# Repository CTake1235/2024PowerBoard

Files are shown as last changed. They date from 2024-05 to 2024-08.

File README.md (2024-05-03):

# 2024PowerBoard
## 緊急停止基板 designed by しーたけ
- 安価で制作が容易（面実装部品は1点のみ）
- 24V/30Aに対応
- ヒューズで過電流を保護
## LED説明
- BATT
  - バッテリー挿入時点灯
  - 作業終了時に切れていることを確認しましょう
- +5V
  - 5V電源供給時に点灯
  - バッテリ接続中消灯の場合DCDCに異常がある可能性があります
- SIG
  - マイコンからの駆動電源オン信号（+3V3HIGH）で点灯
  - 消灯の場合マイコンからの信号がありません
- PWR
  - 駆動電源オン（FETオン）時に点灯
  - 他LEDが正常、駆動電源オン信号で消灯の場合FETに異常があるかもしれません
  - または、ヒューズが飛んでいる可能性があります

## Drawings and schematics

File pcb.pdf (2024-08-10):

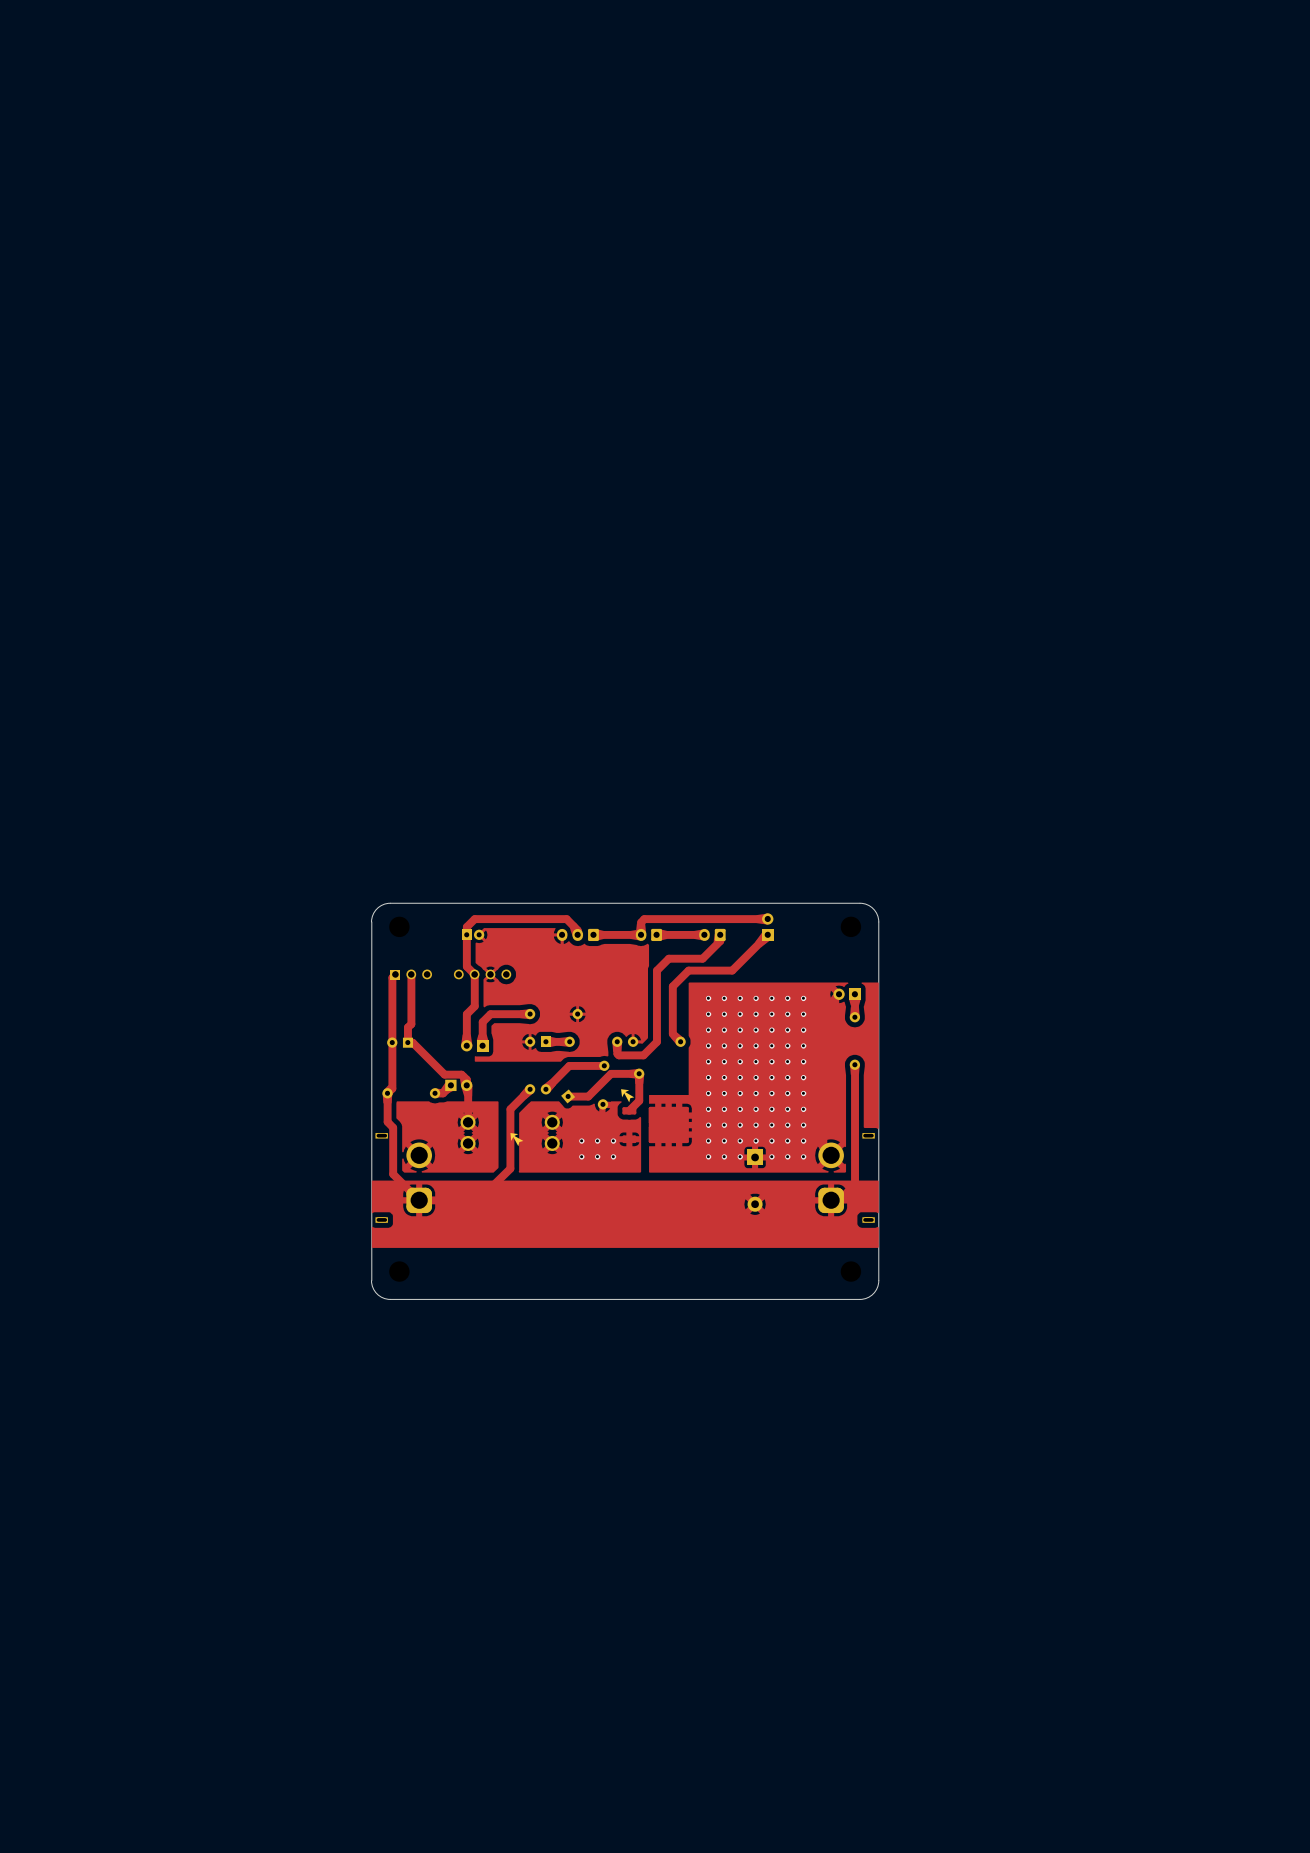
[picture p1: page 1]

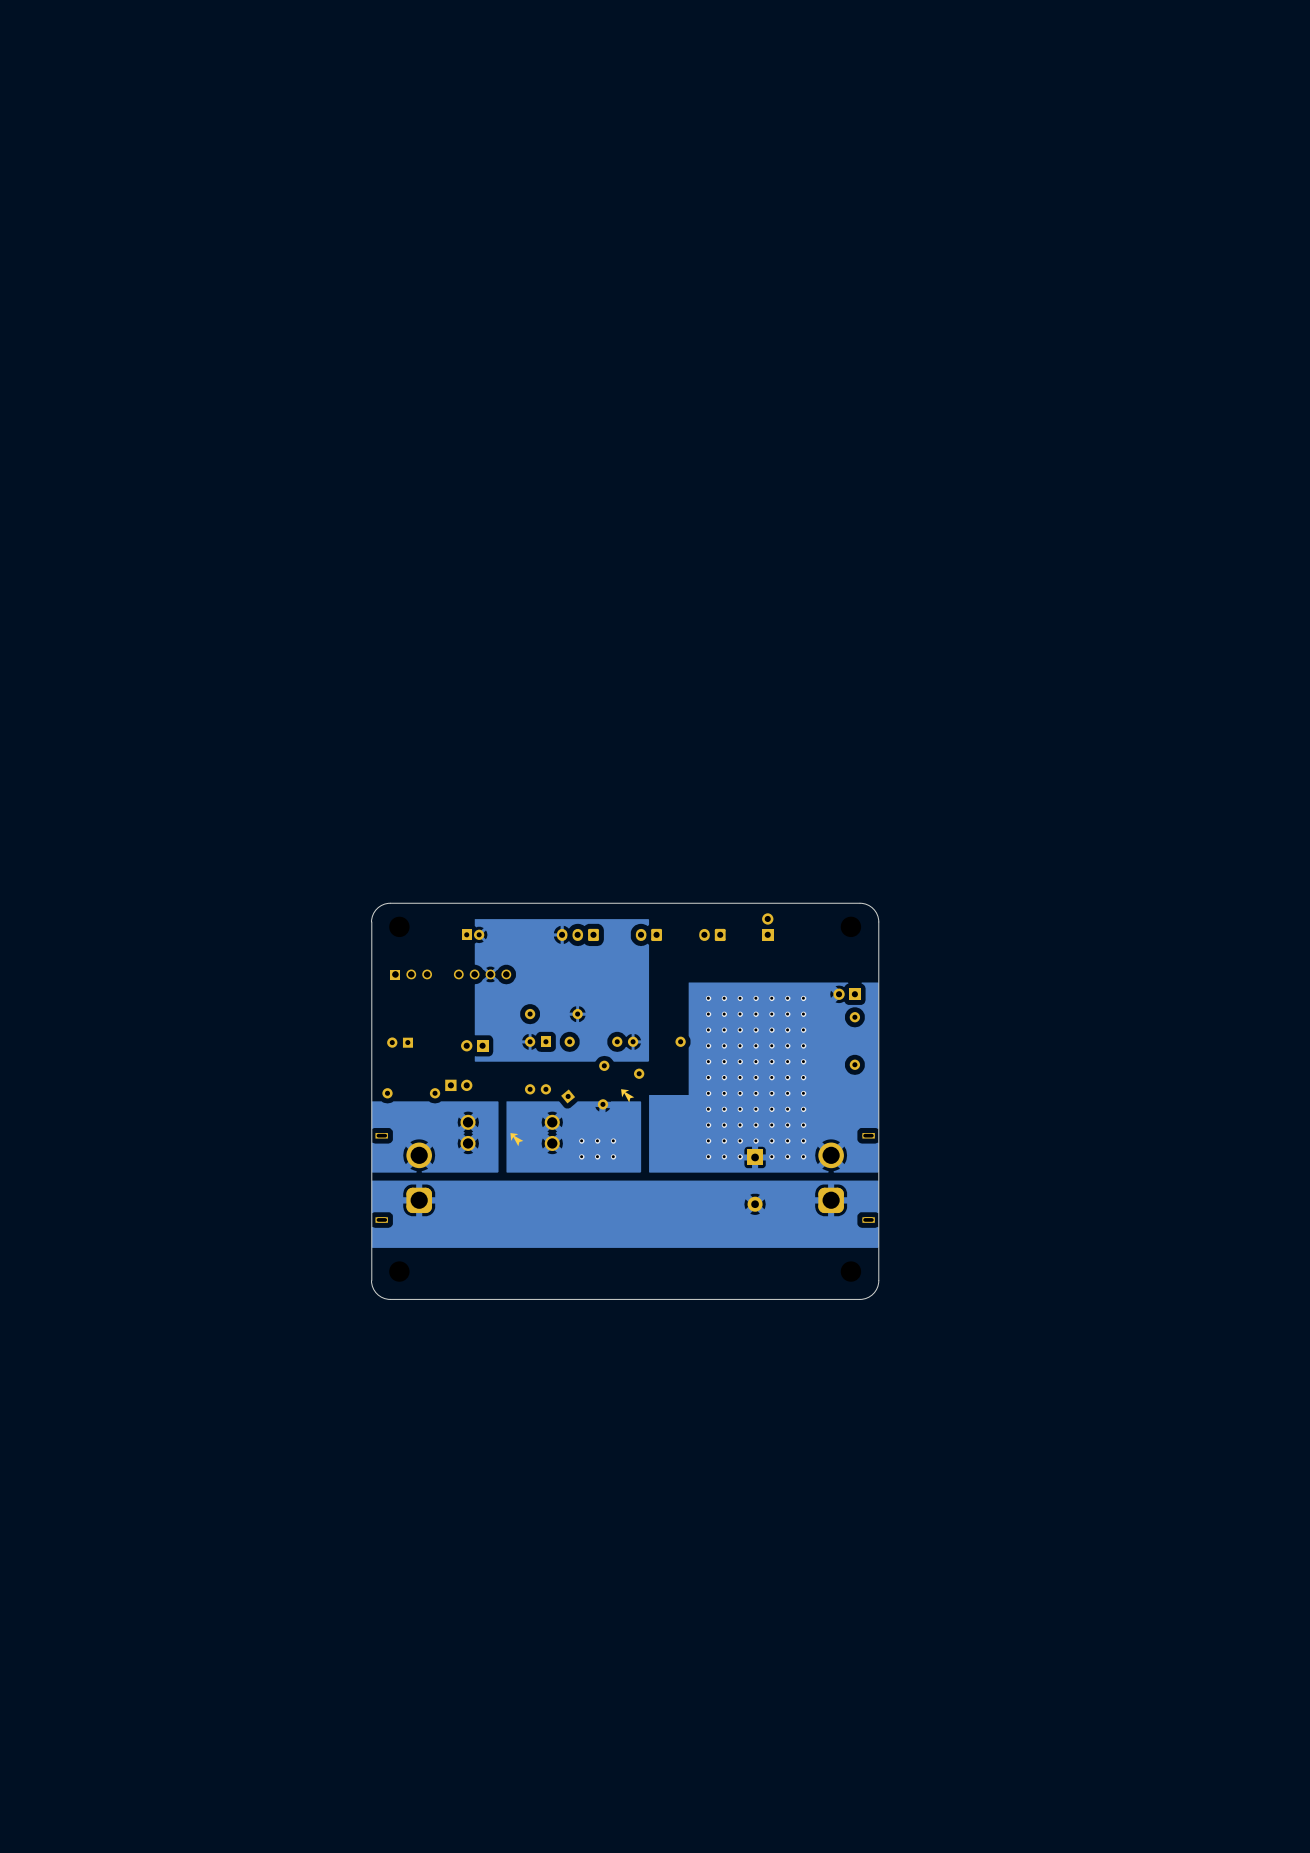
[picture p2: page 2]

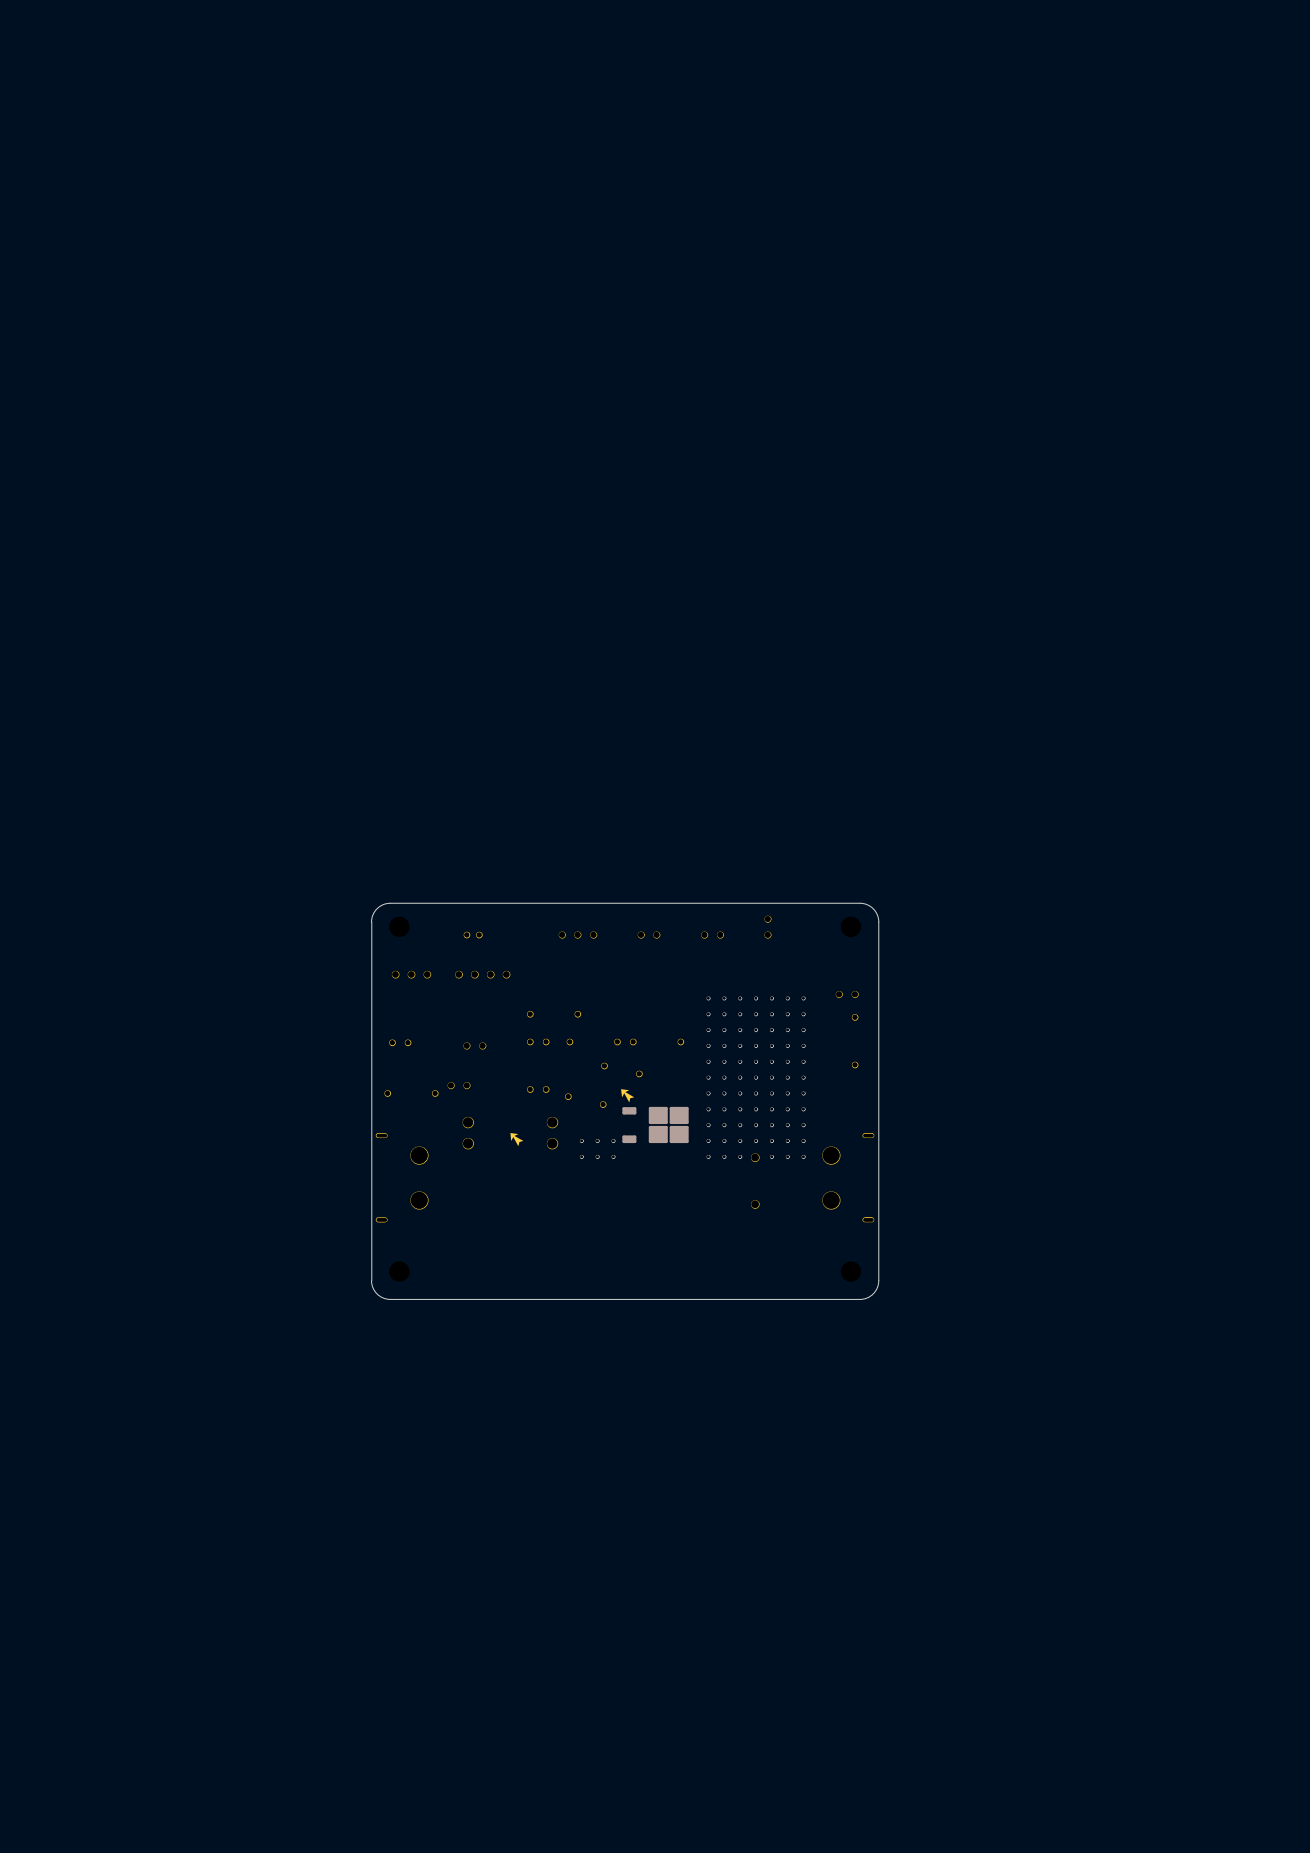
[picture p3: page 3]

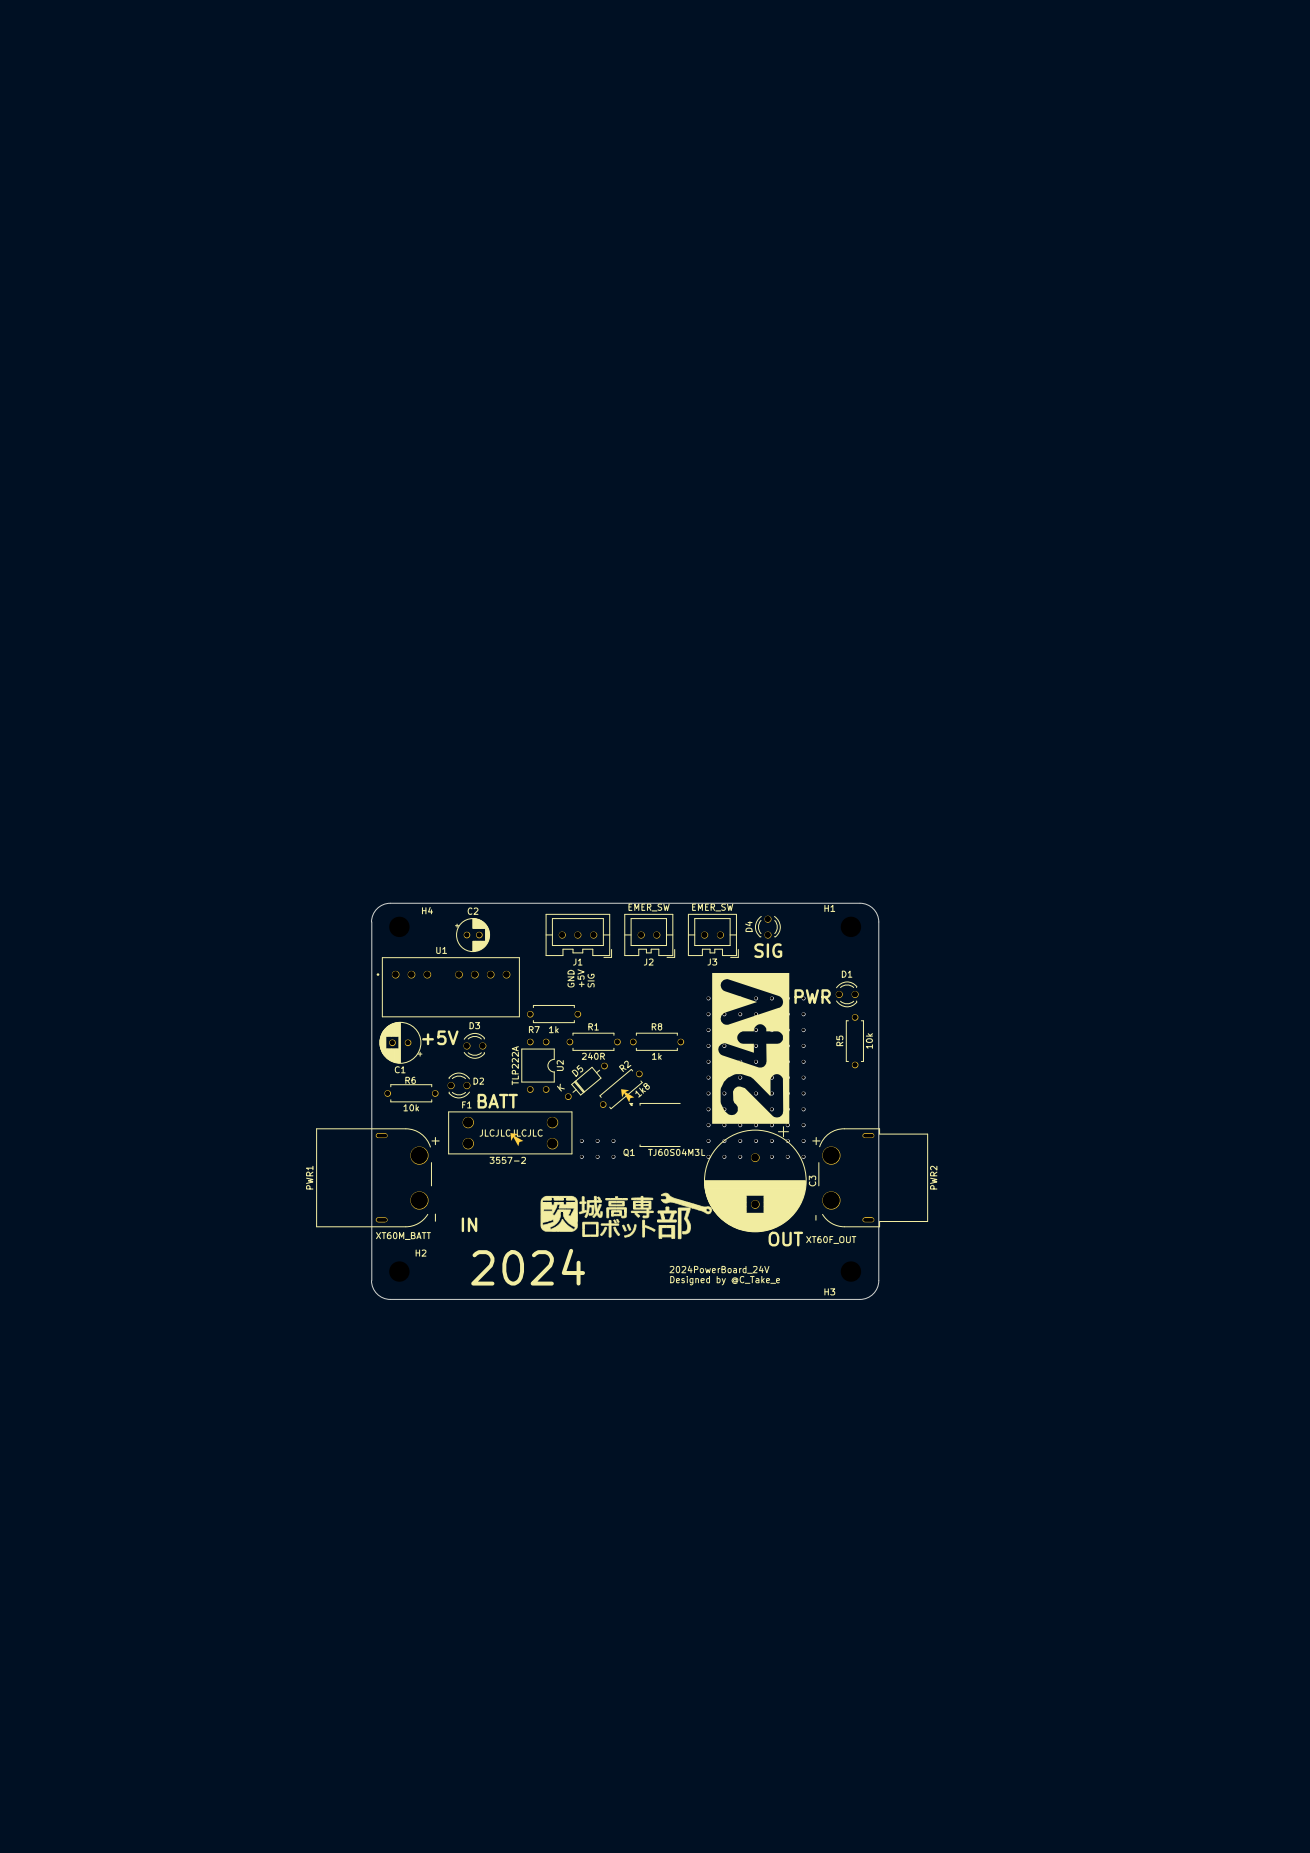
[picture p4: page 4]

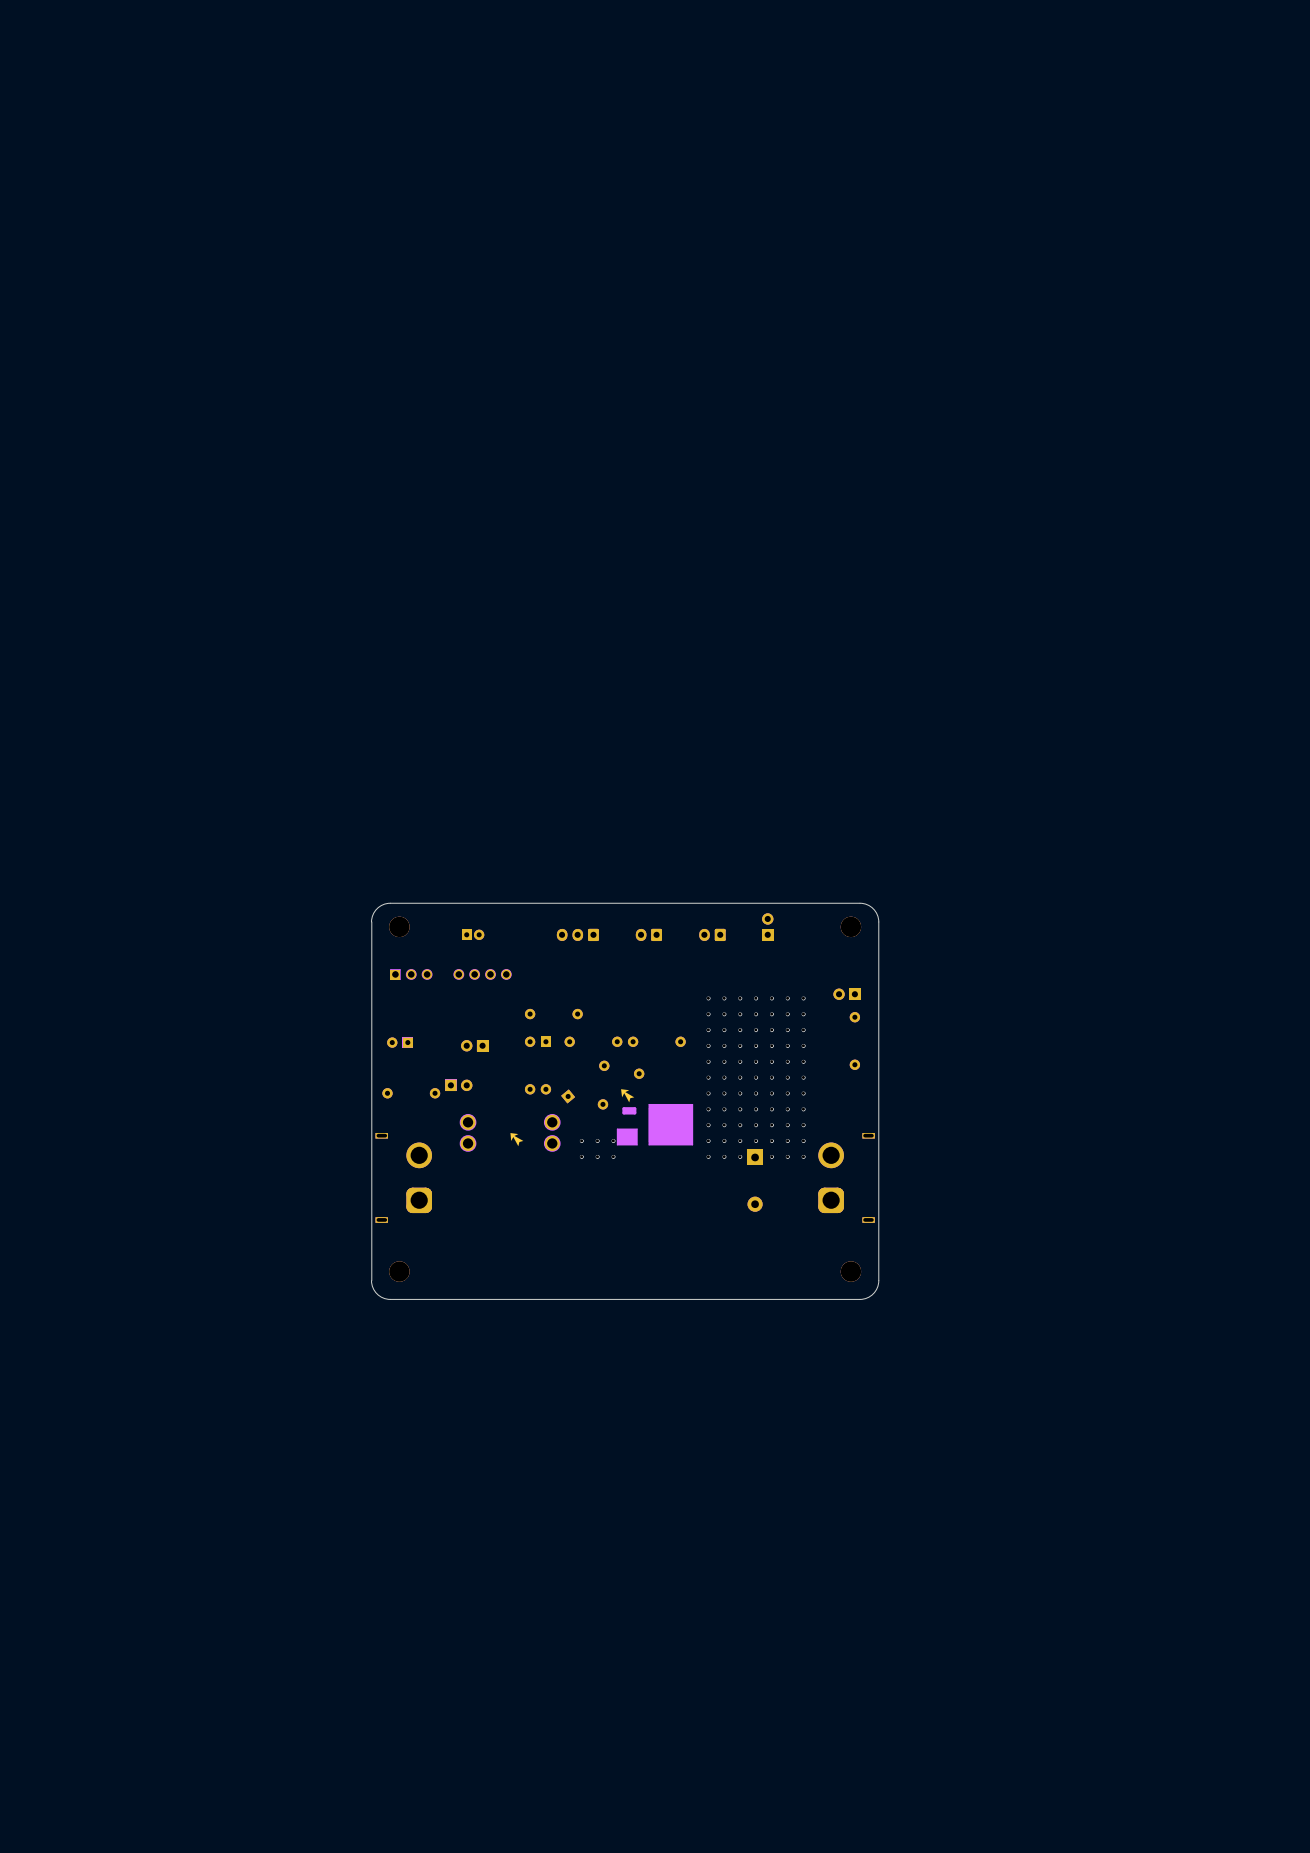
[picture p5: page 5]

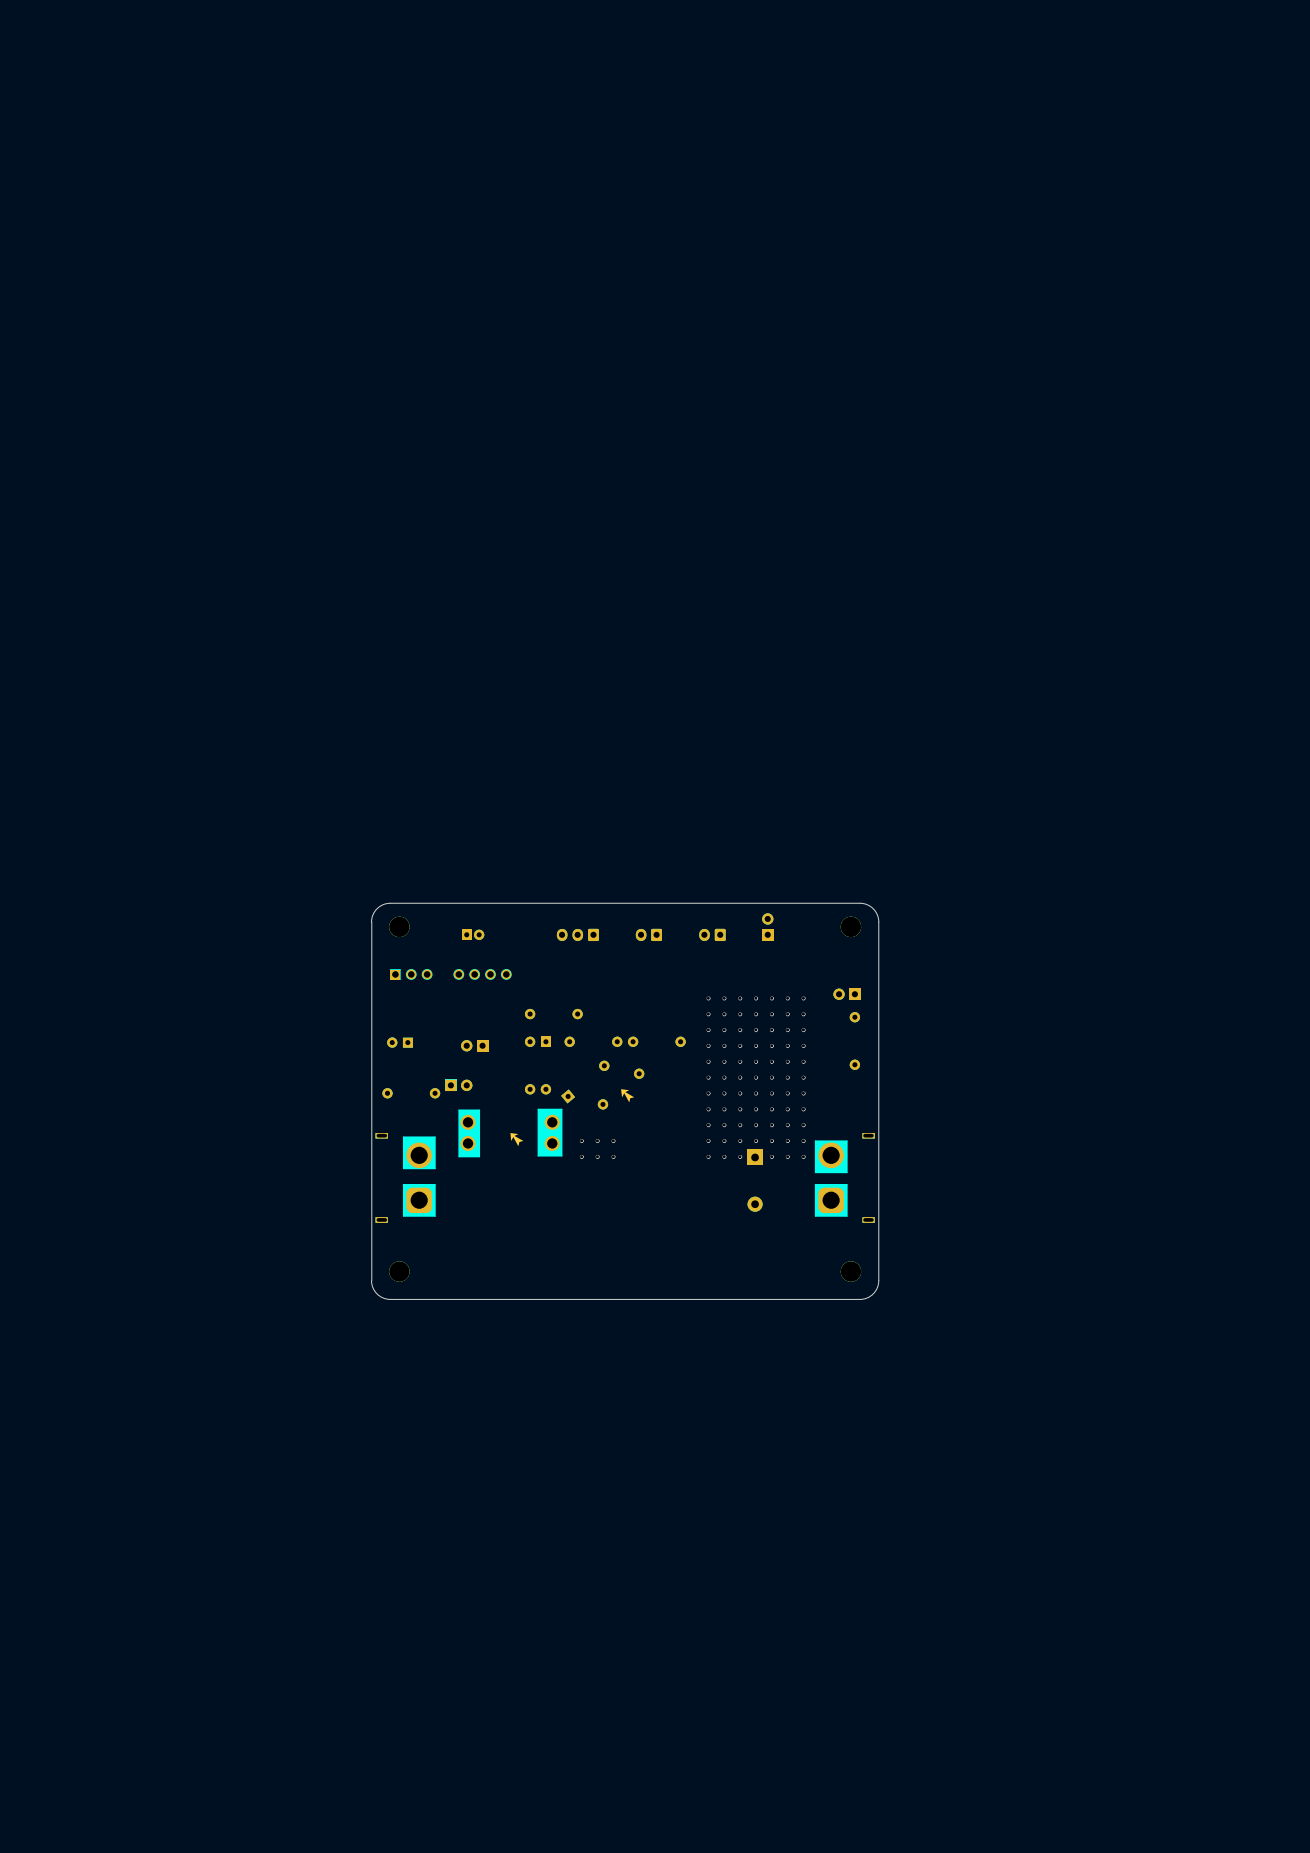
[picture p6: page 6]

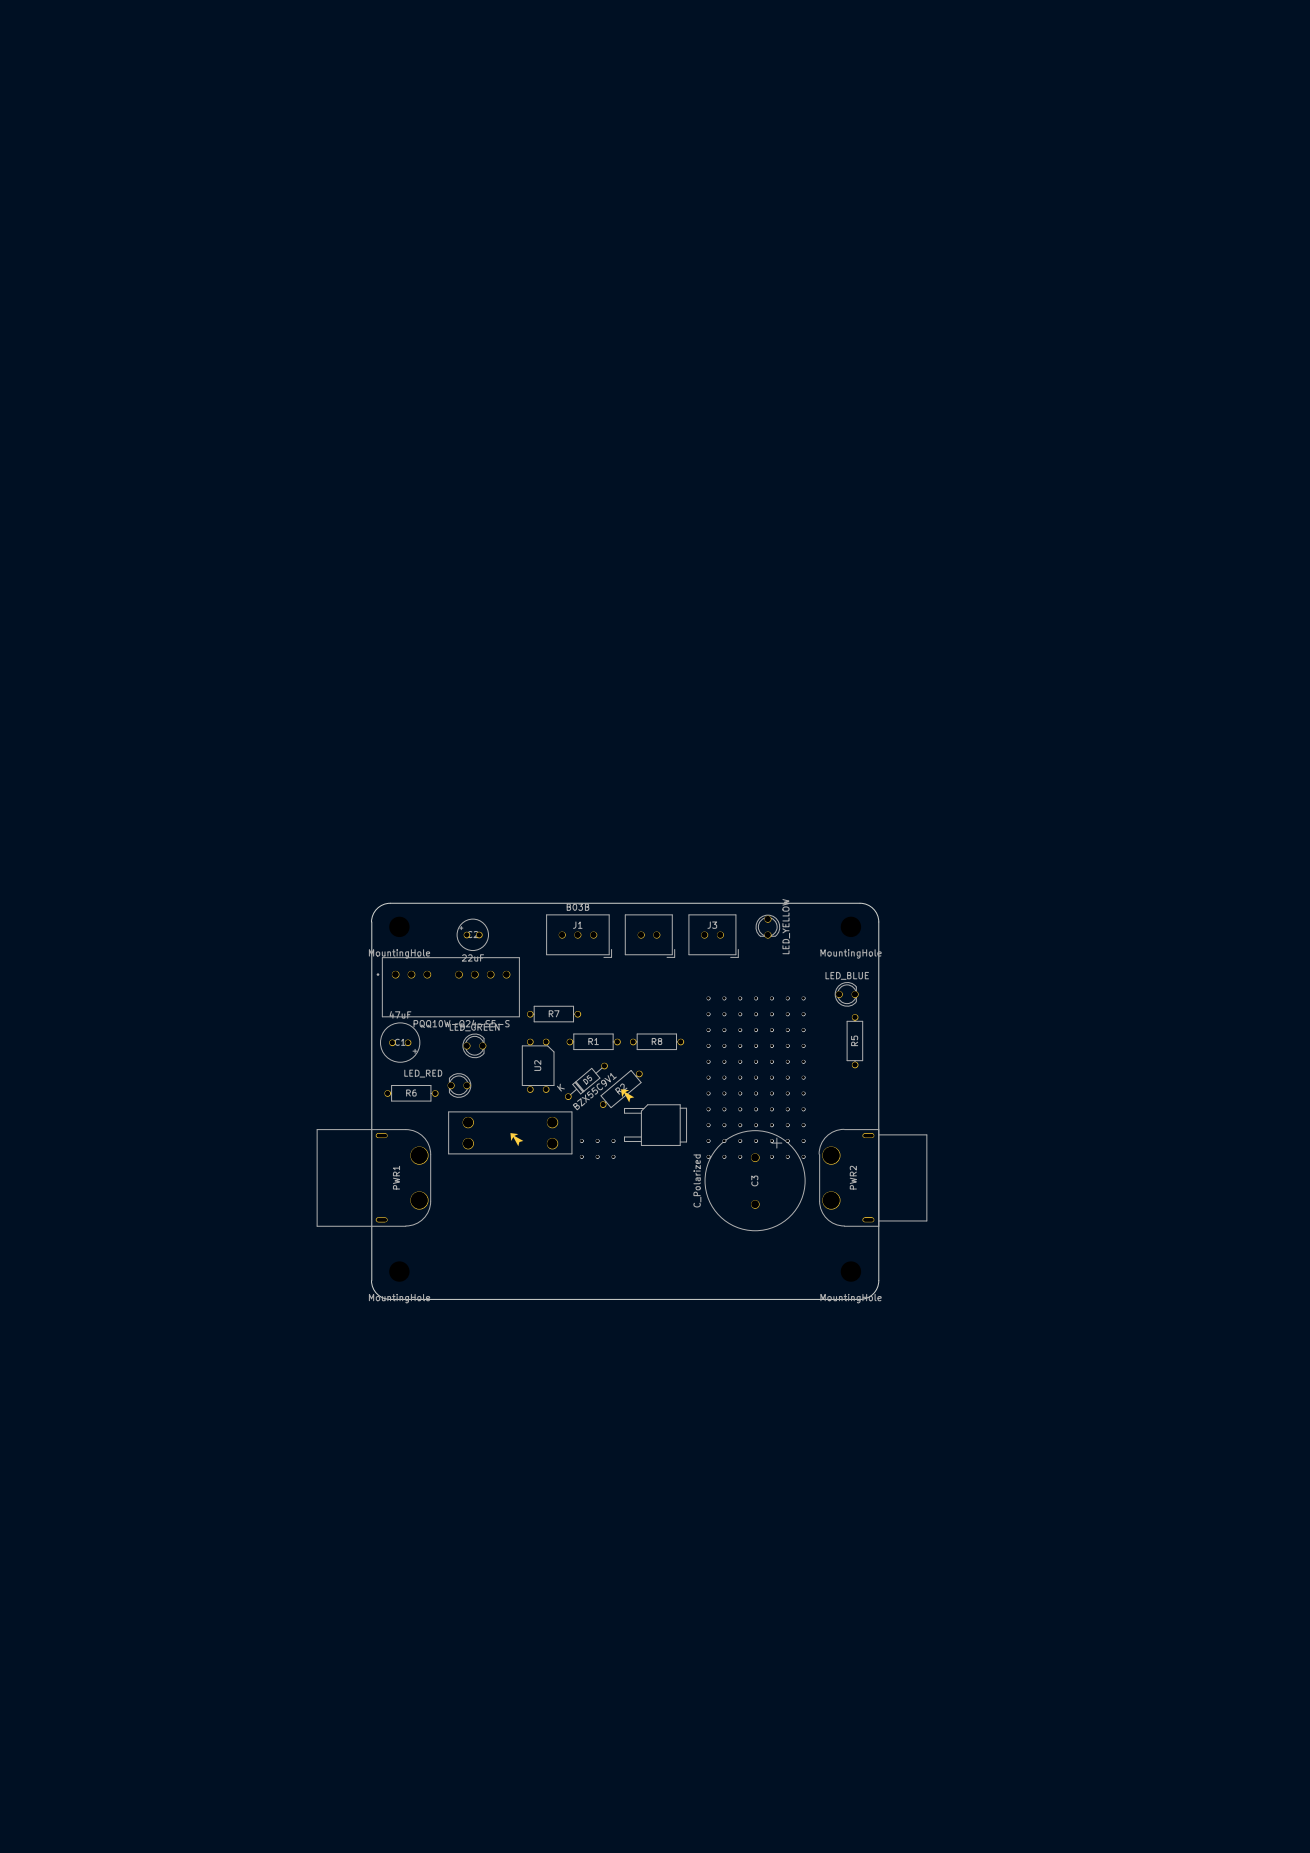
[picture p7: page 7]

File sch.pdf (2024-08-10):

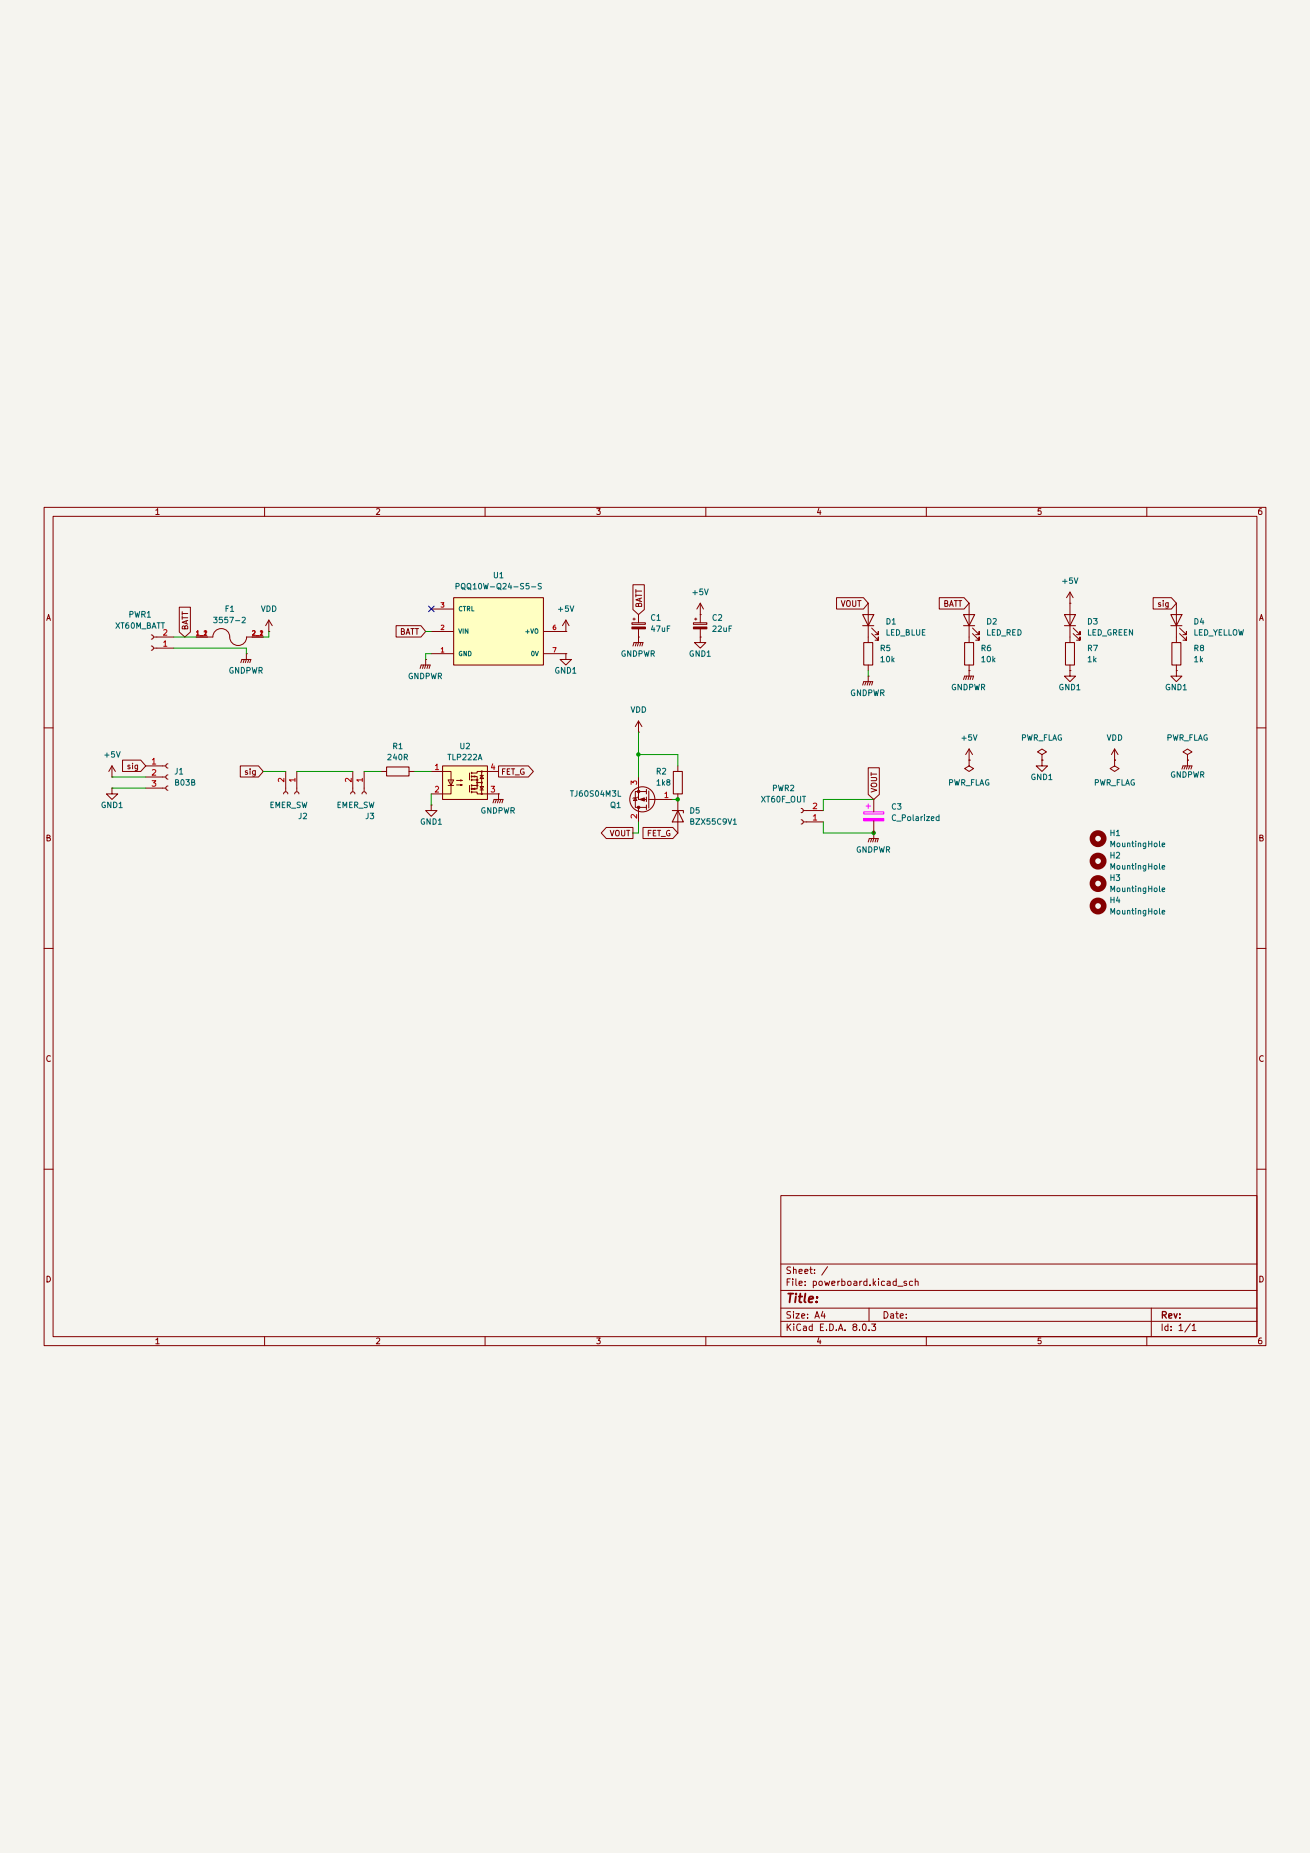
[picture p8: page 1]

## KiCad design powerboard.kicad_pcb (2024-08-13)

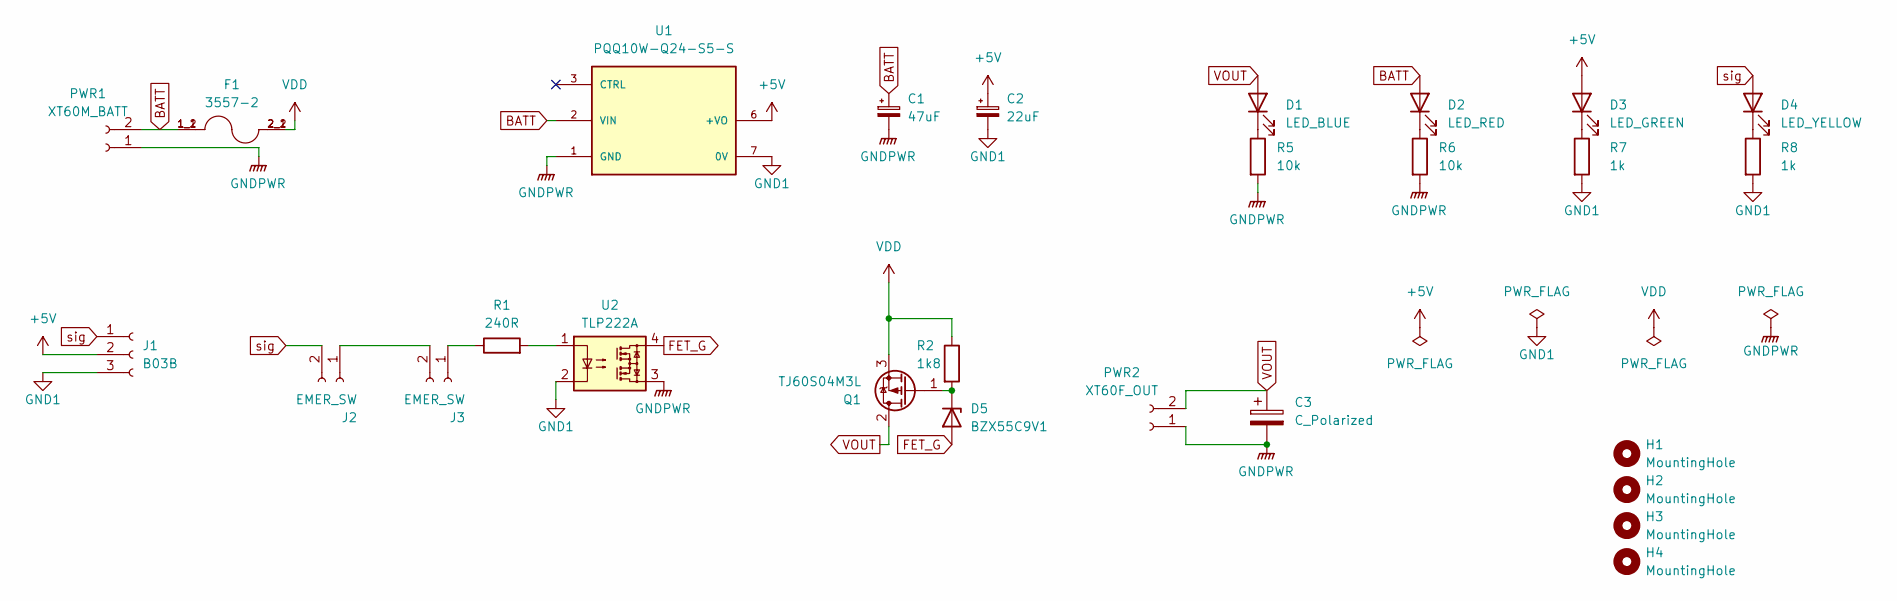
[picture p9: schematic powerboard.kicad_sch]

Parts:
C1: 47uF; CP_Radial_D6.3mm_P2.50mm
C2: 22uF; CP_Radial_D5.0mm_P2.00mm
C3: C_Polarized; CP_Radial_D16.0mm_P7.50mm
D1: LED_BLUE; LED_D3.0mm
D2: LED_RED; LED_D3.0mm
D3: LED_GREEN; LED_D3.0mm
D4: LED_YELLOW; LED_D3.0mm
D5: BZX55C9V1; D_DO-35_SOD27_P7.62mm_Horizontal
F1: 3557-2; FUSE_3557-2; PARTREV D
H1, H2, H3, H4: MountingHole; MountingHole_3.2mm_M3_Pad_Via
J1: B03B; JST_XA_B03B-XASK-1_1x03_P2.50mm_Vertical
J2, J3: EMER_SW; JST_XA_B02B-XASK-1_1x02_P2.50mm_Vertical
PWR1: XT60M_BATT; AMASS_XT60PW-M_1x02_P7.20mm_Horizontal
PWR2: XT60F_OUT; AMASS_XT60PW-F_1x02_P7.20mm_Horizontal
Q1: TJ60S04M3L; TO-252-2
R1: 240R; R_Axial_DIN0207_L6.3mm_D2.5mm_P7.62mm_Horizontal
R2: 1k8; R_Axial_DIN0207_L6.3mm_D2.5mm_P7.62mm_Horizontal
R5, R6: 10k; R_Axial_DIN0207_L6.3mm_D2.5mm_P7.62mm_Horizontal
R7, R8: 1k; R_Axial_DIN0207_L6.3mm_D2.5mm_P7.62mm_Horizontal
U1: PQQ10W-Q24-S5-S; CONV_PQQ10W-Q24-S5-S; PARTREV 1.0
U2: TLP222A; DIP-4_W7.62mm

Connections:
+5V: C2.1, D3.2 (A), J1.2, U1.6 (+VO)
BATT: C1.1, D2.2 (A), F1.1_1, F1.1_2, PWR1.2, U1.2 (VIN)
FET_G: D5.2 (A), U2.4
GND1: C2.2, J1.3, R7.2, R8.2, U1.7 (0V), U2.2
GNDPWR: C1.2, C3.2, PWR1.1, PWR2.1, R5.2, R6.2, U1.1 (GND), U2.3
unnamed: D1.1 (K), R5.1
unnamed: D2.1 (K), R6.1
unnamed: D3.1 (K), R7.1
unnamed: D4.1 (K), R8.1
unnamed: D5.1 (K), Q1.1 (G), R2.2
unnamed: J2.1, J3.2
unnamed: J3.1, R1.1
unnamed: R1.2, U2.1
VDD: F1.2_1, F1.2_2, Q1.3 (S), R2.1
VOUT: C3.1, D1.2 (A), PWR2.2, Q1.2 (D)
sig: D4.2 (A), J1.1, J2.2

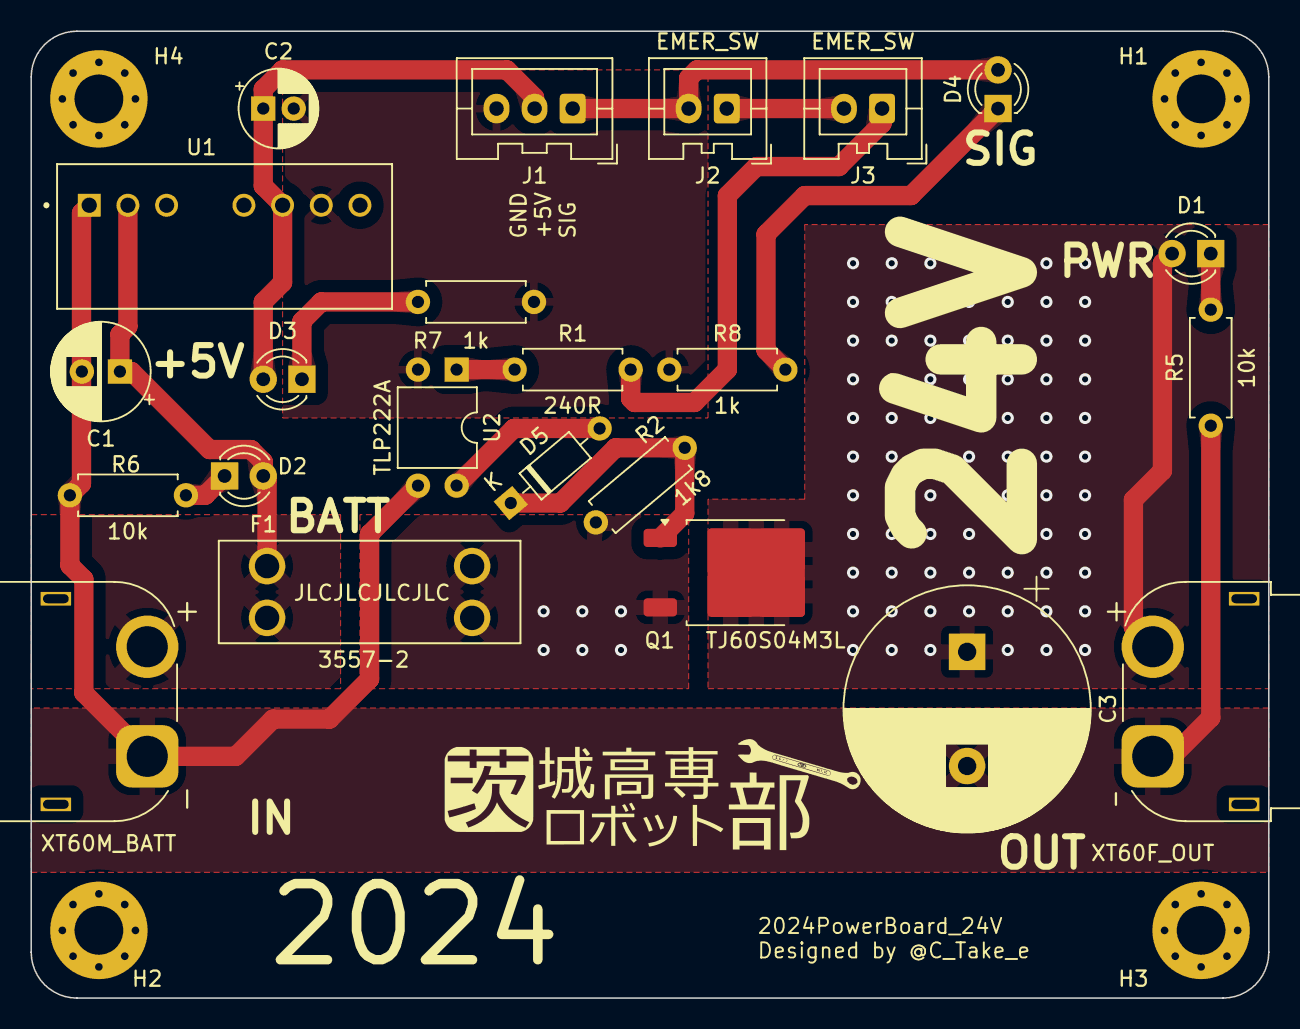
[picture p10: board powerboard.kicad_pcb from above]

Board: 2 copper layers, 81.3 x 63.5 mm, 27 parts (0 on the bottom side), 16 nets.

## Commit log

2024-04-06 pcb/sch: add a hole, silks
    [powerboard.kicad_pcb, powerboard.kicad_sch]
2024-04-06 sch: change Capacitance C1 (Power)
    [powerboard.kicad_sch]
2024-04-06 pcb: update with sch, add CUTE RESISTOR
    [powerboard.kicad_pcb]
2024-04-06 pcb: add vias
    [powerboard.kicad_pcb]
2024-04-06 pdf: update with pcb
2024-04-06 pcb/pdf: printed gerb
    [powerboard.kicad_pcb]
2024-04-07 pcb: change angle of CUTE RESISTOR
    [powerboard.kicad_pcb]
2024-04-08 pcb: add teardrops
    [powerboard.kicad_pcb]
2024-04-08 pcb: put vias under FET
    [powerboard.kicad_pcb]
2024-04-08 pcb:add vias on VOUT, from FET to OUT
    [powerboard.kicad_pcb]
2024-04-08 pcb: moved silk of FET value
    [powerboard.kicad_pcb]
2024-04-09 pcb: make more margin between J2 & R3
    [powerboard.kicad_pcb]
2024-04-09 Revert "pcb: make a margin between J2 & R3"
    This reverts commit 403c4a9d61e7e79612fd97e349d6792e48dc765a.
    [powerboard.kicad_pcb]
2024-04-09 pcb: make a margin
    [powerboard.kicad_pcb]
2024-04-09 pcb: add vias behind source
    [powerboard.kicad_pcb]
2024-04-09 pcb: make the outline wider, move holes
    [powerboard.kicad_pcb]
2024-04-09 pcb: Leave space between J1, J2, and J3
    [powerboard.kicad_pcb]
2024-04-09 pcb/sch: Add FET
    [powerboard.kicad_pcb, powerboard.kicad_sch]
2024-04-09 Revert "pcb/sch: Add FET"
    This reverts commit 0032eebc1d6eb9ed2a957a3795ce5049efafd74e.
    [powerboard.kicad_pcb, powerboard.kicad_sch]
2024-04-09 pcb: Delete vias under FET
    [powerboard.kicad_pcb]
2024-04-09 pcb: Delete vias under a FET
    This reverts commit e1503daf84bd5df3be65f05229be8e469e7dccfe.
    [powerboard.kicad_pcb]
2024-04-09 pcb: BIG VOUT
    [powerboard.kicad_pcb]
2024-04-09 pcb: BIGGER VOUT
    [powerboard.kicad_pcb]
2024-04-09 pcb: Small fix for GND1 zone
    [powerboard.kicad_pcb]
2024-04-10 pcb:Finishing touches
    [powerboard.kicad_pcb]
2024-05-03 PCB: 分圧抵抗を追加、アノテーションをリセット
    [powerboard.kicad_sch]
2024-05-03 PCB: DCDCを変更
    [powerboard.kicad_sch]
2024-05-03 PCB: DCDCの位置調整
    [powerboard.kicad_pcb, powerboard.kicad_sch]
2024-05-03 PDF: SCH/PCBの更新を反映
2024-05-03 PCB: 微調整
    [powerboard.kicad_pcb]
2024-05-03 PDF: 更新
2024-05-18 発注用にゾーン塗りなおし
    [powerboard.kicad_pcb]
2024-05-18 クソデカ24Vシルク追加
    [powerboard.kicad_pcb]
2024-08-10 ツェナーで定電圧チャレンジ
    [powerboard.kicad_pcb, powerboard.kicad_sch]
2024-08-10 ツェナー回り修正、DCDC入力コンデンサ位置変更
    [powerboard.kicad_pcb, powerboard.kicad_sch]
2024-08-10 コンデンサ追加、フップリ修正
    [powerboard.kicad_pcb, powerboard.kicad_sch]
2024-08-13 あれこれ
    [powerboard.kicad_pcb, powerboard.kicad_sch]
